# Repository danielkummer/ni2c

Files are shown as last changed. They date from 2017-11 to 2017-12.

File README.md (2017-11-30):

# Nixie i2c Driver

This simple, custom nixie driver is indented to drive  _any_ kind of nixie tubes via i2c interface. It allows to address two  tubes with each i2c slave. The module is intended to be stackable and dynamically addressable using dip switches.

* Supports up to 8 stacked drivers
* Each driver module can power 2 nixie tubes

The driver module has been tested with the following nixie tubes:

* IN-4
* IN-7

## BOM - Bill of Materials

| Name | Count | Component | Description |
| ---- | ----- | --- | --- |
| 74141 | 2x | SN74141 or K155ID1 | BCD decoder |
| PCF8574 | 1x | PCF8574 | i2c I/O expander |
| SW1/SW2 | 1x | DIP Switch 4 | |
| R1, R2 | 2x | 10kΩ Resistor | bus pull-up |
| R3, R4, R5, R8 | 4x | 10kΩ Resistor | |
| R6, R7 | 2x | 10kΩ 2W Resistor | |
| C2, C3, C4| 3x | 0.1µF Capacitor | optional |
| STACK PWR | 1x | pin-2 Male/female pin header | use male header with long pins to stack the module. Use a short pinned header for the bottom module |
| HV PWR | 1x | pin-2 Male/female pin header | use male header with long pins to stack the module. Use a short pinned header for the bottom module |
| PWR | 1x | screw terminal  | optional, power can also be supplied via STACK PWR |
| I2C | 1x | pin-2 Male/female pin header | i2c bus, 1:SDA 2:SCL |
| NX1, NX2 | 2x | pin-8 Male pin header | 90° angle for stackable module |
| ANODE | 1x | pin-6 Male pin header | 90° angle for stackable module |

## Schema

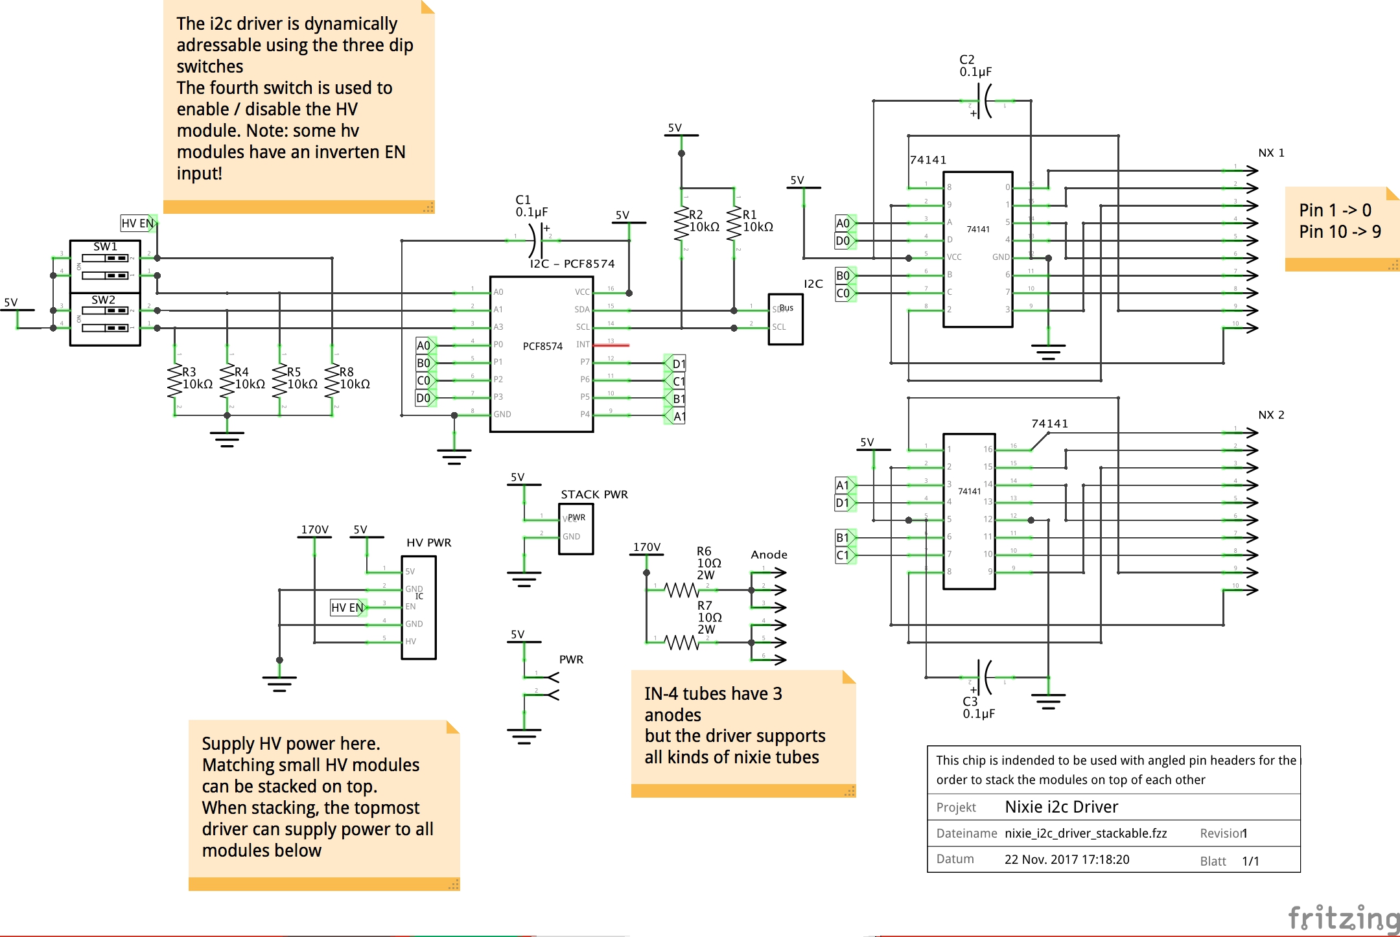
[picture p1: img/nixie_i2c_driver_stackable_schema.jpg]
description


## Assembly instructions

* The capacitors are optional as they're used as bypass

## Problem Solving

* If the tubes don't light up correctly you might have to change R6, R7. You can use [this calculator](http://www.csgnetwork.com/anoderescalc.html) to determine the resistor values based on the HV power supply

## I2c Interface Definition

| Byte | 7(MSB) | 6 | 5 | 4 | 3 | 2 | 1 | 0(LSB) |
| ---- | --- | - | - | - | - | - | - | --- |
| i2c slave address | L | H | H | H | A2 | A1 | A0 | R/W |
| I/O data bus | P7 | P6 | P5 | P4 | P3 | P2 | P1 | P0 |

### Address Reference

* Only the write addresses are shown as the nixie driver module doesn't support read operations.
* Arduino uses 7-bit addresses, the LSB (R/W) is _not_ set and the address range starts at 0x38

| A2 | A1 | A0 | i2c bus 8-bit slave address |
| -- | -- | -- | --- |
| L | L | L | 0x70 |
| L | L | H | 0x72 |
| L | H | L | 0x74 |
| L | H | H | 0x76 |
| H | L | L | 0x78 |
| H | L | H | 0x7A |
| H | H | L | 0x7C |
| H | H | H | 0x7E |

## BCD Decoder Reference

The two bcd decoders each use 4-bit of the 8-bit I/O expander.

The 74141 decoder has 4 inputs marked A,B,C,D which trigger corresponding outputs.

### Truth Table

| D | C | B | A | Output |
| - | - | - | - | --- |
| L | L | L | L | 0 |
| L | L | L | H | 1 |  
| L | L | H | L | 2 |
| L | L | H | H | 3 |
| L | H | L | L | 4 |
| L | H | L | H | 5 |
| L | H | H | L | 6 |
| L | H | H | H | 7 |
| H | L | L | L | 8 |
| H | L | L | H | 9 |

All values above 0x9 are out of range and turn all outputs off.

* "on" range: 0x0..0x9
* "off" range: 0xA..0xF

## Using the Nixie i2c module

Based on the logic tables of the bcd decoders, writing to the i2c bus to output numbers is quite simple.

One byte defines the values for both decoders:

| Decoder | Bits |
| --- | ---- |
| NIXIE 1 | 0000ABCD |
| NIXIE 2 | ABCD0000 |

### Data Examples

| Example value | Nixie Output |
| --- | --- |
| 0xFF | all off |
| 0x12 | "21" |
| 0x01 | "10" |

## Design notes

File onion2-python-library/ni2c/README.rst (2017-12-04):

 NI2C - Universal nixie driver
--------

For use with the Omega2, you need to supply the i2c class
in the constructor in order for it to work...

To use , simply do::

    >>> import ni2c
    >>> nixie ni2c.Ni2c(onionI2C.OnionI2C(), 2)
    >>> nixie.write("1234")

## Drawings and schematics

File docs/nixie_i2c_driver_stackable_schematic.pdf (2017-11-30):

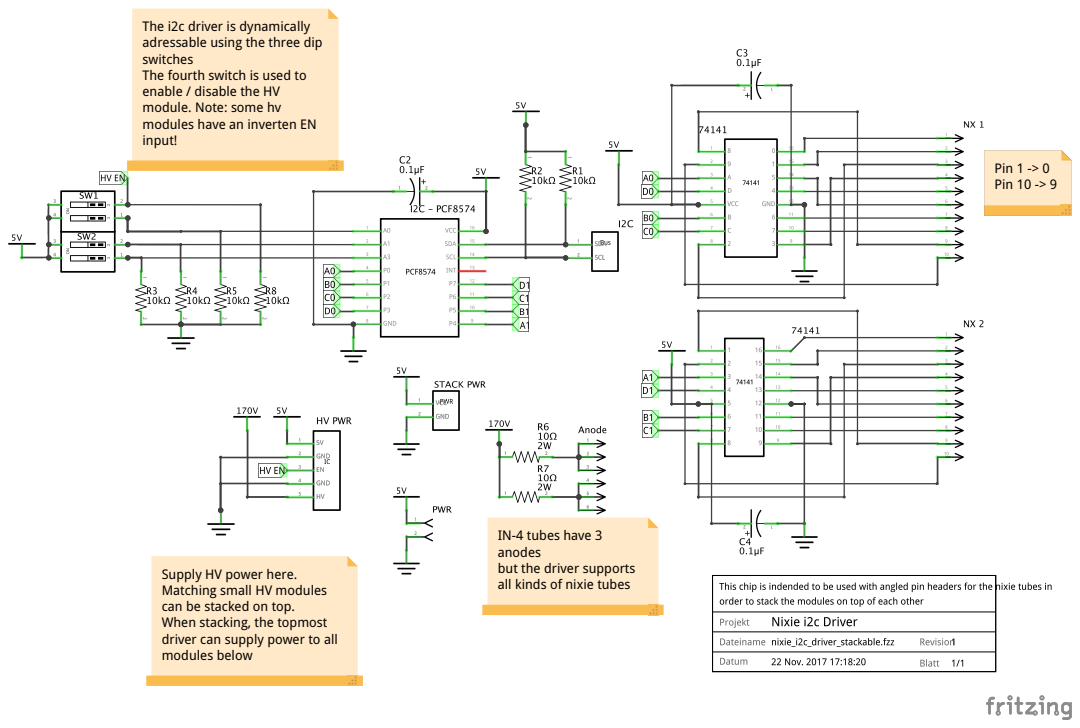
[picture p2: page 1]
Pin 1 -> 0 Pin 10 -> 9

The i2c driver is dynamically
adressable using the three dip
switches
The fourth switch is used to
enable / disable the HV
module. Note: some hv
modules have an inverten EN
input!

IN-4 tubes have 3
anodes
but the driver supports
all kinds of nixie tubes

Supply HV power here.
Matching small HV modules
can be stacked on top.
When stacking, the topmost
driver can supply power to all
modules below

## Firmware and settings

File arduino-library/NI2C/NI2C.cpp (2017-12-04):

//
//    FILE: NI2C.cpp
//  AUTHOR: Daniel Kummer
//    DATE: 09-nov-2017
// VERSION: 0.1.0
// PURPOSE: I2C nixie module library for arduino
//     URL: [TODO]
//
// HISTORY:
// 0.1.0 initial version
//

#include "NI2C.h"

#include <Wire.h>

NI2C::NI2C(const uint8_t numberOfModules = 1, const uint8_t startAddress = 0x38, bool debug = false)
{
        _numberOfModules = numberOfModules;
        _debug = debug;
        _startAddress = startAddress;
        _error = NI2C_OK;
        _dataOut = 0xFF;
}

void NI2C::debug(const bool debug = true) {
        _debug = debug;
}

void NI2C::begin()
{
        Wire.begin();
}

void NI2C::write(const char* value)
{
        //2 chars per module
        uint8_t numOfChars = strlen(value);
        if(numOfChars > _numberOfModules * 2) {
                _error = NI2C_MAX_MODULE_ERROR;
                return;
        }

        for(uint8_t i = 0; i < numOfChars; i++) {
                uint8_t module = getModuleForCharPosition(i);
                byte address = getI2cAddress(module);

                char c = value[i];

                int value = 0;
                if(isdigit(c)) {
                        //Trick to map ASCII characters to integer value
                        value = c - '0';
                } else {
                        value = mapCharToValue(c);
                }


                /*
                hack - we only write "full bytes" - e.g if the 3rd param is >= 1
                that's why for the last character if it's uneven we write directly
                */
                uint8_t nixieIndex = i % 2;
                //is last character and uneven
                if (i == numOfChars - 1 && nixieIndex == 1) {
                  nixieIndex = 2;
                }

                byte result = write8(address, value, nixieIndex);
                if(result > 0) {
                        _error = result;
                        break; //break for loop - don't write more!
                }
        }
}

void NI2C::off() {
        for(uint8_t i = 1; i < _numberOfModules; i++) {
                write8(getI2cAddress(i), 0xff, 2);
        }
}

uint8_t NI2C::write8(const uint8_t address, const uint8_t value, const uint8_t nixieIndex)
{
        switch(nixieIndex) {
        case 0:
                _dataOut = _dataOut & 0x0F | (value << 4);
                break;
        case 1:
                _dataOut = _dataOut & 0xF0 | value;
                break;
        default:
                _dataOut = value;
                break;
        }

        if(_debug) {
                Serial.print("i2c address: ");
                Serial.print(address);
                Serial.print(" value: ");
                Serial.println(_dataOut);
        }


        /*
        note we only want to write "full" bytes to not make the tubes "flicker"
        because one part of the byte has "old" values from the previous write
        */
        uint8_t result = NI2C_OK;
        if(nixieIndex > 0) {
          Wire.beginTransmission(address);
          Wire.write(_dataOut);
          result =  Wire.endTransmission();
          if(_debug) {
                  Serial.print("Transmission status: ");
                  Serial.println(result);
          }
        }
        return result;

}

/**
 * Returns addresses 0x70, 0x72, 0x74, ... 0x7E
 */
uint8_t NI2C::getI2cAddress(uint8_t moduleNumber)
{
        uint8_t result = _startAddress + (moduleNumber * 2);
        if(_debug) {
                char outBuffer[4];
                sprintf(outBuffer, "%02X", result);
                Serial.print("I2C address [");
                Serial.print(outBuffer);
                Serial.print("] -> module (");
                Serial.print(moduleNumber);
                Serial.println(")");
        }
        return result;
}

uint8_t NI2C::getModuleForCharPosition(uint8_t charPosition)
{
        long in_min = 0.0;
        long in_max = MAX_MODULES * 2.0;
        long out_min = 1.0;
        long out_max = MAX_MODULES * 1.0;

        uint8_t result = round((charPosition - in_min) * (out_max - out_min) / (in_max - in_min) + out_min);

        if(_debug) {
                Serial.print("Character position [");
                Serial.print(charPosition);
                Serial.print("] -> module (");
                Serial.print(result);
                Serial.println(")");
        }
}

uint8_t NI2C::mapCharToValue(char c)
{
        //map all non numeric characters to values which can be represented (or set display to off)
        uint8_t result = NIXIE_TUBE_OFF;

        switch(c) {
        case 'n':
                result = 0;
                break;
        case '+':
                result = 1;
                break;
        case 'm':
                result = 2;
                break;
        case 'A':
                result = 3;
                break;
        case 'V':
                result = 4;
                break;
        case 'M':
                result = 5;
                break;
        case 'o':
                result = 6;
                break;
        case 'i':
                result = 7;
                break;
        case 'K':
                result = 8;
                break;
        case '-':
                result = 9;
                break;
        case ' ':
                result = NIXIE_TUBE_OFF;
        default:
                if(_debug) {
                        Serial.print("Unknown character: ");
                        Serial.println(c);
                }
                break;
        }

        if(_debug) {
                Serial.print("Mapped character [");
                Serial.print(c);
                Serial.print("] -> (");
                Serial.print(result);
                Serial.println(")");
        }

        return result;
}

int NI2C::lastError()
{
        int e = _error;
        if(_debug) {
                Serial.print("i2c error: ");
                switch(e) {
                case 0:
                        Serial.println("success");
                        break;
                case 1:
                        Serial.println("data too long to fit in transmit buffer");
                        break;
                case 2:
                        Serial.println("received NACK on transmit of address");
                        break;
                case 3:
                        Serial.println("received NACK on transmit of data");
                        break;
                case 4:
                        Serial.println("other error");
                        break;
                case NI2C_MAX_MODULE_ERROR:
                        Serial.println("maximum number of modules exeeded");
                        break;
                }
        }
        _error = NI2C_OK;
        return e;
}

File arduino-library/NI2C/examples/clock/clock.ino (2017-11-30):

#include "NI2C.h"
#include <Wire.h>

//we're using 4 module to do a simple time display...
NI2C nixie(4);

void setup() {
  Serial.begin(115200);
  
  // put your setup code here, to run once:
  nixie.begin();
}

void loop() {
    int hours = 0;
    int minutes = 0;
    int seconds = 0;
  
    char outBuffer[9];
    sprintf(outBuffer, "%02d %02d %02d", hours, minutes, seconds);
    
    nixie.write(outBuffer);
    
    seconds++;

    if(minutes == 59 && seconds == 59) { 
      hours++;
      minutes = 0;
    }
    
    if(seconds == 59) {
      minutes++;
      seconds = 0;
    }

   delay(1000);
}

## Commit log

2017-11-30 Add Arduino driver library
2017-11-30 Update README, add fritzing design files
    [nixie_i2c_driver_stackable.fzz, nixie_shift_register_driver.fzz]
2017-12-04 Add python library for use with Omega2 and i2c
